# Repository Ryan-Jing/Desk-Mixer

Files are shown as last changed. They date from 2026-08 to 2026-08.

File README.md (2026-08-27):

# Desk-Mixer

A desk-top two-deck music mixer. Two tracks play at once; physical faders, knobs and buttons let
you crossfade, filter and vary the tempo of each while an LCD shows what is loaded. A companion
app on your laptop puts music on it.

Built on a **Teensy 4.1** on a custom PCB.

---

## Repository

| Path | What |
|---|---|
| [`Firmware/`](Firmware/) | Firmware — PlatformIO, C++ |
| [`App/`](App/) | Companion app — Python + PySide6 |
| [`Electrical/`](Electrical/) | Schematics and board — KiCad |
| [`Docs/`](Docs/) | Engineering source of truth |
| [`Tools/`](Tools/) | Cross-project code generation and checks |

## Hardware at a glance

| Function | Part |
|---|---|
| MCU | Teensy 4.1 — i.MX RT1062, 600 MHz Cortex-M7 |
| Audio codec | SGTL5000 → 3.5 mm jack, via I2S1 |
| Bluetooth audio | BM83SM1-00TA, fed digitally over I2S2 |
| Storage | microSD, native 4-bit SDIO |
| Power | USB-C → TUSB320 CC → TPS259251 eFuse → TPSM82903 buck |

Both I2S peripherals run at once, so the analog and Bluetooth outputs are independent and
Bluetooth needs no analog round trip.

## How music gets on it

```
Spotify playlist  ──►  metadata only (titles, artists, ISRC)
                            │
                    TrackResolver  ──►  a local audio file you own
                            │
                    ffmpeg  ──►  16-bit 44.1 kHz stereo WAV
                            │
                    USB serial  ──►  SD card  /library/<playlist>/<track>.wav
```

Spotify is never asked for audio — that is a deliberate boundary, not a gap.
See [ADR 0004](Docs/decisions/0004-track-resolver.md).

## Quick start

```sh
# firmware
cd Firmware
pio run -e teensy41            # build
pio test -e native             # host unit tests (once suites exist)

# companion app
cd ../App
python3 -m venv .venv && .venv/bin/python -m pip install -e '.[dev]'
.venv/bin/ruff check .         # tests and type checks once modules exist
```

Enable the shared pre-push gate once:

```sh
git config core.hooksPath .githooks
```

## Documentation

| Read this | For |
|---|---|
| [architecture.md](Docs/architecture.md) | how the three pieces fit together |
| [pinout.md](Docs/pinout.md) | the Teensy pin map — source of truth |
| [audio-architecture.md](Docs/audio-architecture.md) | the audio graph, timing and CPU budget |
| [protocol.md](Docs/protocol.md) | the app ↔ device wire protocol |
| [sd-layout.md](Docs/sd-layout.md) | what lives on the card |
| [testing.md](Docs/testing.md) | the test strategy, and what it deliberately does not cover |
| [decisions/](Docs/decisions/) | why things are the way they are |
| [claude-setup-guide.md](Docs/claude-setup-guide.md) | configuring Claude Code for this repo |

## Two things worth knowing up front

**USB audio out does not work.** The USB-C on the host header has no software path: `USBHost_t36`
has no USB Audio Class driver, none exists for Teensy, and the host stack's isochronous support is
unreliable. The firmware reports that output as unavailable rather than pretending.
[ADR 0005](Docs/decisions/0005-usb-host-audio.md) covers the alternatives.

**The BM83 must be switched to Host Mode** with Microchip's Config Tool before its UART responds
to anything. It ships in Embedded Mode. [ADR 0003](Docs/decisions/0003-bluetooth-bm83.md).

## Status

| Area | State |
|---|---|
| Firmware | **scaffolding only** — bare superloop in `main.cpp`, builds clean. Module breakdown deliberately undecided |
| Companion app | **scaffolding only** — design and build order in [`App/README.md`](App/README.md) |
| Wire protocol | **specified**, with generators for both sides written but parked until each side picks a layout |
| Display | **panel not yet chosen** |
| Control surface | provisional pin map; `Interface.kicad_sch` is empty |
| PCB | 36 footprints placed, **no routing yet** |

Firmware is written by Ryan, with the architecture worked out collaboratively — integration notes
per subsystem are in [`Firmware/README.md`](Firmware/README.md). The app is unbuilt; its design and
a step-by-step build order are in [`App/README.md`](App/README.md).

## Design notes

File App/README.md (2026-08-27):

# Desk-Mixer — Companion App

Reads your Spotify playlists, finds the audio, converts it to the format the device plays, and
transfers it over USB.

**Status: scaffolding only.** `pyproject.toml` and an empty package. Nothing is implemented. This
README is the design and the build order — follow it top to bottom.

---

## What it does

```
Spotify Web API          OAuth 2.0 + PKCE, read-only scopes
      │                  playlists, titles, artists, durations, ISRCs
      ▼
TrackResolver            given metadata, return a local audio file
      │                  the extension point — see below
      ▼
ffmpeg                   → 16-bit 44.1 kHz stereo WAV
      │
      ▼
Serial transfer          FILE_BEGIN → FILE_CHUNK ×N → FILE_END, CRC-32 verified
      │
      ▼
device SD card           /library/<playlist>/<track>.wav
```

Spotify supplies **metadata only**. It is never asked for audio — see
[ADR 0004](../Docs/decisions/0004-track-resolver.md).

---

## Setup

```sh
python3 -m venv .venv
.venv/bin/python -m pip install -e '.[dev]'
```

`ffmpeg` must be on PATH (`brew install ffmpeg`).

⚠️ **A venv hardcodes absolute paths.** If this directory is ever moved or renamed, delete `.venv`
and recreate it — the console scripts will otherwise point at the old location.

---

## Build order

Each step is independently testable and depends only on the ones above it. Resisting the urge to
start with the UI is the single most useful discipline here — it is the thinnest layer and the most
likely to change.

| # | Build | Why here | Needs |
|---|---|---|---|
| 1 | **Wire protocol** — framing, CRC-16, decoder | Pure byte-in/byte-out. Fully testable with zero dependencies, and the reference vectors already exist | nothing |
| 2 | **Transport** — serial + a loopback fake | The fake is what lets steps 7–8 be built and tested without hardware | pyserial |
| 3 | **Transcode** — ffmpeg wrapper | Small, self-contained, and the output format is already fixed | ffmpeg |
| 4 | **Resolver interface** + local-library resolver | Defines the contract before anything depends on it. No network | mutagen |
| 5 | **Spotify auth + client** | First step needing credentials and network | requests, a client ID |
| 6 | **YouTube resolver** | Slots into the step-4 contract | yt-dlp |
| 7 | **Manifest + library index** | Needs the resolver to have something to record | — |
| 8 | **Transfer orchestration** | Ties 1–7 together | — |
| 9 | **UI** | Last. Thin by design | PySide6 |

A useful checkpoint: after step 3 you can transcode a file by hand; after step 8 you have a working
CLI and the device can be loaded. The UI is genuinely optional until then.

---

## Layering

```
spotify/     OAuth PKCE + Web API client   — metadata only, never audio
resolve/     TrackResolver contract + implementations
transcode/   ffmpeg wrapper
device/      protocol, transport, transfer
library/     playlist manifests, SD index
ui/          PySide6 views
```

**`ui/` may call anything; nothing may call `ui/`.** Everything else must be usable headless —
that is what makes it testable and what keeps a CLI possible. If logic is hard to test, it is
almost always in the wrong layer.

---

## Implementation notes

### 1. Wire protocol

Full spec in [`Docs/protocol.md`](../Docs/protocol.md). Opcodes and constants come from
`Tools/protocol.toml` — generation is currently parked, so either hand-write them and keep them in
step, or point `PY_OUT` in `Tools/generate_protocol.py` at wherever the module should live and let
it emit them.

```
┌──────┬────────┬──────────────┬───────────────┬───────────┐
│ sync │ opcode │ length (LE16)│  payload      │ crc (LE16)│
│ 0xA5 │  1 B   │     2 B      │  0..512 B     │    2 B    │
└──────┴────────┴──────────────┴───────────────┴───────────┘
```

CRC is **CRC-16/CCITT-FALSE** (poly `0x1021`, seed `0xFFFF`) over *opcode + length + payload* —
everything except the sync byte. Max payload 512 bytes, matching the USB high-speed CDC packet.

The decoder must **discard anything that is not a sync byte while idle**. That is what lets the link
recover after a corrupt frame instead of one dropped byte killing a long transfer.

> **Pin these with tests from the start.** The firmware implements the same framing independently,
> so these vectors are what turn a silent divergence into a failing test:
> ```
> crc16(b"123456789")                     == 0x29B1
> encode(FILE_CHUNK, 01 02 03 04 05).hex() == "a52105000102030405" "2af6"
> encode(PING).hex()                       == "a5010000acfb"
> ```

### 2. Transport

Wrap pyserial behind a small `Protocol` interface with `write` / `read` / `close`, then write a
`LoopbackTransport` that records what was written and can hand back scripted replies.

That fake is worth building *before* anything uses it: it lets the whole transfer flow — including
the device rejecting a command — be exercised with no hardware attached. Teensy USB VID is `0x16C0`
for port auto-detection.

### 3. Transcode

The device plays one format only, so every source funnels through this:

```
ffmpeg -hide_banner -loglevel error -nostdin -y -i <src>
       -map a:0 -vn -ar 44100 -ac 2 -acodec pcm_s16le -f wav <dst>
```

**Build the argument vector separately from running it.** Then the command can be asserted in tests
without invoking ffmpeg, which keeps the test suite fast and hermetic.

Size estimate for space checks before a transfer: `44 + (duration_ms × 44100 / 1000) × 2 × 2` bytes,
about **10 MB per minute**. Check free space before starting — a part-written track is worse than
one never started.

On failure, delete the partial output. A truncated WAV fails at play time, far from the transfer
that caused it.

### 4. Resolver

The extension point that keeps the core neutral about where audio comes from:

```python
class TrackResolver(Protocol):
    name: str
    def resolve(self, track: TrackMeta) -> ResolveResult: ...
```

Two rules that matter:

- **Never raise for an unresolvable track.** Return a failed result carrying a *reason*. One bad
  track must not abort a playlist of sixty.
- **Report the best failure**, not the last one, when everything misses — the user needs to know
  *why* nothing matched.

`LocalLibraryResolver` matches **ISRC first** (exact, confidence 1.0), then normalised
artist/title. Normalisation should strip accents, punctuation, and **bracketed qualifiers** —
"Song (Remastered 2011)" and "Song [Live]" are the single largest cause of false negatives across
catalogues. Fall back to filename parsing (`Artist - Title.ext`) when tags are missing; a file
without tags is not an error.

### 5. Spotify

OAuth 2.0 with **PKCE** — this is a desktop app and therefore a public client, so there is no
secret to protect. Scopes are read-only: `playlist-read-private`, `playlist-read-collaborative`.
The app must never request write access.

- Verifier: 64 random bytes, base64url, unpadded. Challenge: S256 of the verifier, base64url,
  unpadded.
- Redirect to a **loopback** URI (`http://127.0.0.1:<port>/callback`); carry an opaque `state` and
  check it on return.
- Endpoints: `GET /v1/me/playlists`, `GET /v1/playlists/{id}/tracks`. Both paginate — follow `next`.
- Skip `is_local` tracks and null entries; playlist payloads routinely contain both.
- Pull **ISRC** from `external_ids` — it is by far the most reliable match key.

⚠️ **Access is single-user.** Spotify apps stay in development mode (~25 manually-added users)
unless they grant a quota extension, which they rarely do for non-commercial projects. Accepted:
this is Ryan's own device.

Map the API payload to `TrackMeta` in a **free function**, so it can be tested against captured JSON
with no network.

### 6. YouTube resolver

Slots into the step-4 contract. Two things to plan for:

- **`yt-dlp` breaks whenever the site changes.** Treat it as a dependency needing maintenance, and
  fail with a clear message rather than a stack trace.
- **Matching is the real problem, not downloading.** Covers, live takes and sped-up edits all
  resolve to plausible-looking videos. **Duration is the cheapest sanity check** — reject anything
  more than a few seconds from the Spotify metadata, and prefer results whose title contains the
  artist.

Quality context: lossy → WAV **preserves** the source, it does not improve it. Given the device ends
in SBC Bluetooth or a modest headphone amp, that is a fine trade — see
[ADR 0004](../Docs/decisions/0004-track-resolver.md).

### 7. Manifest

Written beside the audio on the card. Records what *should* be present, **including what could not
be resolved and why**, so a later sync does not have to re-derive intent from filenames.

```json
{
  "name": "Late Night Set",
  "source_id": "spotify:playlist:...",
  "entries": [
    { "title": "...", "artist": "...", "remote_path": "/library/Late Night Set/....wav",
      "isrc": "...", "duration_ms": 449000, "resolver": "local" }
  ],
  "unresolved": ["Some Track — not found in local library"]
}
```

The firmware does not read it — it enumerates directories directly, so the card works even if the
manifest is stale or missing. This is for the app and for humans.

### 8. Transfer

```
FILE_BEGIN (uint32 size, utf-8 path) ──► ACK
FILE_CHUNK (≤512 B)                  ──► ACK    … repeated
FILE_END   (uint32 crc32)            ──► ACK
```

CRC-32 is IEEE 802.3 (`zlib.crc32`), computed over the whole file. The device verifies before
committing and deletes the partial file on mismatch.

⚠️ **Never transfer while the device is playing.** SD write bursts stall the reads feeding the audio
engine, which is the classic dropout cause. The firmware should enforce this as a hard interlock,
but the app should not attempt it either.

Names are sanitised to **ASCII** before writing: transliterate accents (`Björk` → `Bjork`), replace
anything else with `_`, and never produce an empty name. The firmware holds names in fixed byte
buffers and renders them with a simple font, so a multi-byte character risks being truncated
mid-sequence.

### 9. UI

Thin. It owns no business logic — everything it shows comes from the headless layers. A playlist
list, a transfer button, a progress bar and a status line covering device presence and ffmpeg
availability is enough for v1.

---

## Testing

```sh
.venv/bin/python -m pytest
.venv/bin/ruff check . && .venv/bin/mypy
```

**No test may touch the network, a real serial port, or a real ffmpeg binary.** That is achievable
throughout if the layering above holds:

| Area | How to test it hermetically |
|---|---|
| protocol | reference vectors, round trips, corruption, resynchronisation |
| transport | `LoopbackTransport` playing a fake device that ACKs or NACKs |
| transcode | assert the argument vector; never invoke ffmpeg |
| resolver | a `tmp_path` folder of dummy audio files |
| spotify | captured JSON payloads through the mapping function |
| transfer | loopback fake, including the rejection paths |

Write the protocol tests **first** — they are the contract with the firmware, and they cost nothing
to run.

---

## Configuration and secrets

Nothing secret belongs in the repository. PKCE needs no client secret, but a **client ID** from the
Spotify developer dashboard is required.

```
~/.config/desk-mixer/settings.json        client ID, music folders, serial port, ffmpeg path
~/.config/desk-mixer/spotify-token.json   cached token — chmod 0600
```

Use `platformdirs` rather than hardcoding, and make loading tolerant of a missing or corrupt file by
falling back to defaults.

A `--doctor` command that reports ffmpeg availability, visible serial ports, configured music
folders and whether a client ID is set is worth building early — it must work **without PySide6**,
so import the UI lazily.

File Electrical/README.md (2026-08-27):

# Desk-Mixer — PCB

KiCad 10 project (`Desk-DJ`). **Four-layer**, 1.6 mm FR4.

> **This directory is hand-edited in KiCad.** Nothing else in this repository modifies it, and
> tooling should not either — editing `.kicad_sch` or `.kicad_pcb` as text corrupts UUIDs and net
> linkage.

## Sheets

| Sheet | State |
|---|---|
| `USB_Input.kicad_sch` | USB-C power input: `USBLC6-2SC6` ESD → `TUSB320` CC → eFuse |
| `Power.kicad_sch` | `TPS259251` eFuse → `TPSM82903` buck → +3V3. Most complete sheet |
| `Microcontrollers.kicad_sch` | Teensy 4.1 pin budget assigned; BM83 placed but unwired |
| `Audio_IO.kicad_sch` | SGTL5000 I2S/I²C/headphone out, `SJ1-3525N` jack. No power section yet |
| `LCD.kicad_sch` | **empty** |
| `Interface.kicad_sch` | **empty** |

The board has 36 footprints imported and **no tracks, pours or outline**.

Four layers rather than two: the stackup has to give an uninterrupted ground plane under the USB
differential pairs and both I2S MCLK lines. Those are 11.29 MHz square waves running near the
analog section, and on two layers you end up choosing which of impedance control or analog
isolation to compromise.

## What firmware depends on

The pin map lives in [`Docs/pinout.md`](../Docs/pinout.md) and
`Firmware/include/config.h`, both derived from this schematic.

**If they disagree with the schematic, the schematic wins.** Flag the discrepancy rather than
editing either side silently.

## BM83 — what the board must provide

Use **`BM83SM1-00TA`** (Audio Transceiver firmware, A2DP source), not `-00AB` (speaker linking).

Beyond I2S2 and the UART, three control lines need Teensy GPIOs: `MFB` (26), `RST_N` (43) and
`P3_4` (31). `P3_4` and `RST_N` are what let the Teensy put the module into flash mode and act as a
serial relay for Microchip's PC tools — which is how a soldered module stays recoverable without a
programming header or USB traces to the module.

No copper, traces or components beneath the module's PCB antenna.

## Open items

A read of the netlist on 2026-08-26 turned up several things worth checking next time this is
open — an I²C net-name mismatch, a power-button symbol that is actually an LDO, the SGTL5000's
missing power section, and the unwired BM83 among them. They are recorded in
[ADR 0006](../Docs/decisions/0006-electrical-review.md) as reference, not as a task list.

## Portability warning

Every non-stock symbol and footprint resolves through the **global** KiCad library table at
`~/Local/System-Local/Packages/KiCad/…`, outside this repository. Cloning the repo on another
machine will break all of them. Vendoring the project libraries under this directory would fix it.

## Ignored files

`.gitignore` excludes KiCad's per-user state: `*.kicad_prl`, `fp-info-cache`, `*-backups/`,
`_restore_backup_*/`, lock files, and `.history/`. That last one is KiCad 10's Local History,
which keeps its **own nested git repository** — it was previously picked up as a gitlink with no
`.gitmodules`, which breaks `git submodule status`.

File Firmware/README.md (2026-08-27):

# Desk-Mixer — Teensy 4.1 Firmware

Two-deck audio playback, mixing and control-surface handling.

**Status: scaffolding only.** `src/main.cpp` holds a bare superloop and nothing else. The module
breakdown is deliberately undecided — hardware is not finalised, and the structure should follow
the hardware rather than lead it. This README is the integration reference to build against.

---

## Build

```sh
pio run -e teensy41            # build
pio run -e teensy41 -t upload  # flash
pio device monitor             # serial console
pio test -e native             # host unit tests (once suites exist)
```

Current footprint: ~9.5 kB flash, of 7.75 MB. Effectively all of it is still free.

---

## Hardware

| Function | Part | Interface |
|---|---|---|
| MCU | **Teensy 4.1** (i.MX RT1062, 600 MHz Cortex-M7) | — |
| Audio codec | **SGTL5000** | I2S1 + I²C `0x0A` |
| Bluetooth audio | **BM83SM1-00TA** | I2S2 (audio) + UART (control) |
| Storage | microSD | native 4-bit SDIO (`BUILTIN_SDCARD`) |
| Display | SPI panel, **not yet selected** | SPI |
| Host link | USB CDC serial | Teensy device port |

### Clock and data pins — fixed by the silicon

| Bus | MCLK | BCLK | LRCLK | TX | RX |
|---|---|---|---|---|---|
| I2S1 (SAI1) → SGTL5000 | 23 | 21 | 20 | **7** | **8** |
| I2S2 (SAI2) → BM83 | 33 | 4 | 3 | 2 | 5 |

SAI1 and SAI2 are independent peripherals, so **both run at once**. The analog jack and Bluetooth
are fed from separate buses, and Bluetooth gets a digital feed with no analog round trip.

S/PDIF is available on pin 14 and currently unused. Full map: [`Docs/pinout.md`](../Docs/pinout.md).

### USB

- **Device** — the micro-USB port, reached on the PCB via pogo pins to the bottom-side D+/D− test
  pads when the Teensy is seated in its header. Power and data both come from the panel USB-C, so
  the Teensy sees one host and one supply — no pads or traces need cutting, and the board can still
  be flashed standalone through its own micro-USB when removed.
  ⚠️ The receptacle and those pads are the **same electrical node**, so **never connect the panel
  port and the micro-USB at the same time** — that ties two hosts' VBUS together.
- **Host** — the 5-pin header, wired to a USB-C connector for audio out. **There is no USB Audio
  Class host driver for Teensy**, so this path has no software route today. See
  [ADR 0005](../Docs/decisions/0005-usb-host-audio.md).

---

## The superloop

`main.cpp` runs fixed-cadence tasks against `millis()`:

```c
if ((now - s_last_control_ms) >= CONTROL_PERIOD_MS) {
    s_last_control_ms = now;
    control_task();
}
```

Chosen over an RTOS because the Teensy audio library already preempts from an interrupt, so the
loop's only job is to run each task often enough. Fixed cadences make every task's worst-case
latency obvious by reading the file — no priority inversion, no stack sizing, no scheduler to
reason about.

**The one rule: nothing in the loop may block.** No `delay()`, no busy-wait, no spin on a peripheral
flag. A task that needs to wait returns and resumes on the next tick.

### Adding a task

Add a period macro, a `s_last_*_ms` timestamp, and a branch. Keep the cadence honest: a task that
runs every 1 ms must actually complete in well under 1 ms.

Starting cadences, adjust once there is something to measure:

| Task | Period | Why |
|---|---|---|
| control surface | 1 ms | responsiveness — this is what makes the device feel tight |
| host link / UARTs | 2 ms | drain buffers before they overflow, but do not starve controls |
| display | 30 ms | ~33 fps; SPI refresh is expensive and the eye is not |

### When the superloop stops being enough

Watch for: a task that cannot complete inside its cadence, or work that must happen at a precise
time rather than "soon". The usual escalations, roughly in order of cost:

1. **Split the long task** across ticks with a small state machine. Cheapest, and usually enough.
2. **Move it to an interrupt** — `IntervalTimer` for periodic work, or a peripheral ISR.
3. **Use DMA** for bulk transfers, so the CPU is not the bottleneck.
4. **Adopt an RTOS** (`TeensyThreads` or FreeRTOS). Only worth it if several tasks genuinely need
   independent blocking; it brings stack sizing and priority questions the superloop avoids.

The audio engine is already effectively option 2 — it runs from the SAI interrupt regardless.

---

## Integration notes

Reference material for each subsystem. **None of this is implemented.**

### Audio — the 2.9 ms deadline

128 samples at 44.1 kHz means one block every **2.9 ms**, 344 times a second. Every audio object's
`update()` runs inside that window at interrupt priority. Overrunning it does not slow the device
down; it drops audio.

Inside any audio callback: **no heap, no blocking, no `Serial`, no unbounded loops.**

The Teensy Audio Library builds a static graph of `AudioStream` objects wired by `AudioConnection`
objects at file scope. A two-deck mixer shape:

```
player A ─► filter ─┐
                    ├─► mixer L/R ─┬─► AudioOutputI2S  ─► SGTL5000 ─► jack
player B ─► filter ─┘              └─► AudioOutputI2S2 ─► BM83 ─► Bluetooth
```

Practical notes:

- `AudioMemory(n)` allocates the block pool. Start around 60 and tune against
  `AudioMemoryUsageMax()`; if usage reaches the allocation, blocks are being starved.
- `AudioProcessorUsageMax()` gives peak CPU as a percentage. Keep it well under ~70 % so transients
  have headroom.
- `AudioConnection` objects exist purely for their constructor side effect. cppcheck reads them as
  unused, which is why `unusedVariable` is suppressed in `.cppcheck-suppressions`.
- Both I2S outputs can be fed permanently. Muting a sink on output switch causes a click; leaving
  both connected and changing only what the UI calls "active" avoids it.

**Varispeed.** The stock library has no variable-rate SD player. `AudioPlaySdResmp` from
[`teensy-variable-playback`](https://github.com/newdigate/teensy-variable-playback) resamples on the
fly — pitch and tempo move together, like a turntable. Its transport API is narrower than it looks
and is worth reading before designing around it:

- `playWav(path)` is the **only** way to start, and always begins at the configured play-start point
- `stop()` clears the playing flag but **does not rewind**
- there is **no `play()`** and no seek

So resume has to be expressed as *set the play-start point, then re-open*, where `setPlayStart`
takes **frames** (per-channel samples), not bytes or milliseconds:

```c
uint32_t frames = (uint32_t)(((uint64_t)position_ms * 44100u) / 1000u);
player.setPlayStart(play_start_arbitrary, frames);
player.playWav(path);
```

Key-lock (WSOLA time-stretch) costs roughly half a core when active — probably a v2 question.

### SGTL5000

`AudioControlSGTL5000` from the stock library. I²C address `0x0A` by default, `0x2A` if the address
pin is pulled high. `enable()` must succeed before audio flows; treat failure as "no analog output"
rather than a fatal error. `volume()` drives the headphone amp, `lineOutLevel()` the line output.

The codec needs its analog supply and charge-pump capacitors in place before it will respond — NXP
**AN3663** is the reference layout.

### BM83 Bluetooth

The device **transmits** to Bluetooth headphones — the A2DP **source** role. Use the
**`BM83SM1-00TA`**, which ships with Microchip's Audio Transceiver firmware and supports source.
The `BM83SM1-00AB` is the Wireless Concert Technology variant for speaker-to-speaker linking and is
the wrong part here.

The TX encoder is **SBC** at 44.1/48 kHz, so the Bluetooth path is capped at SBC quality regardless
of what is on the card.

**The Teensy is the I2S master; the BM83 is the slave.** MCLK is mandatory in slave mode — the
module is strict about clock synchronisation, and `AudioOutputI2S2` drives it on pin 33.

| Signal | Teensy | BM83 |
|---|---|---|
| BCLK | 21 | `SCLK1` (3) |
| LRCLK | 20 | `RFS1` (2) |
| Audio data out | 2 | `DT1` (4) |
| MCLK | 33 | `MCLK1` (5) |
| UART out | 1 (`TX1`) | `HCI_RXD` (13) |
| UART in | 0 (`RX1`) | `HCI_TXD` (12) |
| Reset | *TBD* | `RST_N` (43) |
| Wake | *TBD* | `MFB` (26) |
| Boot mode | *TBD* | `P3_4` (31) |

⚠️ **Three of those GPIOs are unallocated**, and nothing works without them. `MFB` must go **high
2–3 ms before every UART command** to wake the module from power save; `BM83_EN` is a supply enable
and does not cover it. `RST_N` and `P3_4` are what make in-system flashing possible.

### Provisioning and the serial relay

A fresh `-00TA` already has the right firmware, so what it needs is a **configuration** write:
Host Mode, I2S role **Slave**, I2S path **Input**. Without that the UART does not answer and the
module may try to drive the I2S clocks itself.

Flashing is done by a **PC**, over the module's UART — but it can go **through the Teensy**, which
is the chosen route and needs no extra connector or USB traces to the module:

1. Teensy drives `P3_4` low and pulses `RST_N` → module enters test/flash mode.
2. Teensy runs a transparent serial relay: USB `Serial` ↔ `Serial1`.
3. On the PC, `isUpdate` or the Config GUI Tool selects the **Teensy's COM port**, transport UART.
4. Teensy drives `P3_4` high and resets → app mode.

**The relay is a firmware deliverable.** Small, but it must be transparent about baud and must not
buffer or reorder in a way the tool's timing notices.

An unprovisioned module is silent and gives no diagnostic, so the failure looks exactly like a
wiring fault. Proving the chain on an EVB first separates "not configured" from "wired wrong".

**Antenna keep-out:** no copper, traces or components beneath the module's PCB antenna.

**No Arduino or Teensy library exists**, so the driver is ours. Packet format is in Microchip
**DS50002896A** (*BM83 Host MCU Firmware Development Guide*); reference source, written for PIC32,
is at [`MicrochipTech/bm83_getting_started`](https://github.com/MicrochipTech/bm83_getting_started).

Framing, from that document:

```
[0]    0xAA start byte
[1..2] payload length, BIG-endian, counting opcode + parameters
[3]    opcode
[4..]  parameters
[n]    checksum: two's complement of the sum of every byte after the start byte
```

A well-formed packet's bytes after the start byte sum to zero modulo 256 — that is the property to
verify against. Note the length is **big-endian and counts the opcode**, the opposite of the host
link protocol below; do not copy one codec into the other.

Bluetooth adds 150–300 ms of latency. The wired jack is the monitoring output for beat-matching;
Bluetooth is an audience output, and its metering should not be presented as real-time.

### SD card

Built-in socket on native **4-bit SDIO** via `SD.begin(BUILTIN_SDCARD)` — not SPI, and much faster.
Teensyduino ships `SD 2.0.0` as a wrapper over `SdFat 2.1.2`; drop to `SdFat` directly if you need
its faster APIs or exFAT specifics.

**Audio streams; nothing is loaded whole.** A 4-minute WAV is ~42 MB against 1 MB of RAM, so the
player refills a small buffer from the card while the audio interrupt drains 128 samples every
2.9 ms.

| | |
|---|---|
| One stereo deck | 176.4 kB/s |
| Two decks | **352.8 kB/s** |
| SDIO capability | many MB/s |

So throughput was never the risk — **latency spikes** are. A 32 kB buffer per deck is ~186 ms of
cushion, which is ample against SD read jitter. `AudioPlaySdResmp` buffers more than the stock
player because resampling needs lookahead, and can move that buffer to PSRAM if it is ever needed.

**Never write to the card while playing.** Card write bursts stall reads, and that is the classic
dropout cause. Transfers are rare — a few times a year — so this costs nothing. Make it a hard
interlock in firmware: refuse `FILE_BEGIN` unless both decks are stopped, rather than trusting the
app to behave.

Teensy 4.1 has pads for **8 MB PSRAM**, which can be added later if buffering ever needs it.

Card layout and the WAV-only decision: [`Docs/sd-layout.md`](../Docs/sd-layout.md),
[ADR 0002](../Docs/decisions/0002-wav-not-mp3.md).

### Display

Panel not chosen. Worth keeping the drawing calls behind a small surface of your own so the concrete
driver can be swapped without touching UI logic — the panel decision and the menu logic are
independent problems.

The `DISP_*` nets are already assigned (see the pinout). SPI refresh is slow relative to everything
else, so buffer draws and push once per display tick rather than writing through.

### Control surface

Teensy 4.1 has 18 ADC-capable pins, enough for the full fader/knob budget with no multiplexer.
Encoders belong on the **hardware quadrature timer pins**, where decoding costs zero CPU.

Two things worth handling early, because they are invisible until they annoy you: cheap pots dither
by a couple of counts, so a small hysteresis stops the audio engine being told to change gain every
tick; and pots rarely reach their electrical extremes, so an end deadzone is what makes a closed
fader actually silent.

`Interface.kicad_sch` is still empty, so the pin allocation is provisional.

**Jack insertion is detectable.** `J3` is an `SJ1-3525N`, the tip-and-ring switch variant — the
switches are normally closed to their contacts and open when a plug is inserted. Because the switch
shorts to the audio tip, a plain pull-up reads high in both states; see `Docs/pinout.md` for a
divider that works. Currently unwired and unallocated.

### Host link

USB type is **`USB_MIDI_SERIAL`**, set in `platformio.ini`. That gives a CDC serial port for the
companion app plus a MIDI device, so the mixer can double as a control surface for Mixxx or Traktor.

USB type is compile-time and exclusive — MTP and USB Audio cannot be added to this combination. See
[ADR 0001](../Docs/decisions/0001-usb-port-roles.md).

The wire protocol is specified in [`Docs/protocol.md`](../Docs/protocol.md) and generated from
`Tools/protocol.toml`. The app side is implemented and tested; **the firmware side is not written**.
Generation into the firmware tree is currently switched off — set `H_OUT` in
`Tools/generate_protocol.py` to wherever the header should live to turn it back on.

---

## Structure

`include/` mirrors `src/`, and there is no `lib/` folder. Beyond that the breakdown is open.

One suggestion worth weighing as modules appear: keep the parts that make *decisions* separate from
the parts that touch *hardware*. A file that includes no Arduino or Teensy headers can be compiled
and unit-tested on the laptop, which matters here because of the next section. Framing, checksums,
gain curves, menu logic and format parsing all tend to fall out this way naturally.

To wire a file into host testing, list it in `[pure] sources` in `platformio.ini`.

---

## Testing

| Tier | Command | Covers |
|---|---|---|
| Host unit | `pio test -e native` | anything with no hardware includes |
| On-target | `pio test -e teensy41_test` | SD, I²C, UART, timing |
| Static | `cppcheck` (see `.cppcheck-suppressions`) | whole tree |
| Style | `python3 ../Tools/check_style.py` | house style, mechanically |

**There is no Teensy 4.1 emulator.** No Renode or QEMU machine model exists for the i.MX RT1062,
and the peripherals that matter (SAI/I2S, SDIO) are not modelled anywhere. Host tests over
hardware-independent code, plus fakes for the rest, are the only automated option — which is the
main argument for the split suggested above.

**On-target caveat:** PlatformIO claims the first `Serial` as its test transport, so all `Serial`
use must sit inside `#ifndef UNIT_TEST`. Teensy 4.1 on-target runs are also known to stall after
upload occasionally, so that tier is a local gate, not a CI gate.

CI skips the host-test job while `test/` is empty and picks it up automatically once a suite lands.

---

## Documentation

```sh
doxygen Doxyfile && open doxygen/html/index.html
```

Doxygen emits a "member belongs to two different groups" warning for `main.cpp` — a consequence of
the house style's blank `@name` opening an anonymous member group. Cosmetic.

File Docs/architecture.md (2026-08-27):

# System architecture

## What the device is

A desk-top two-deck music mixer. Two tracks play at once; physical faders, knobs and buttons let
you crossfade, filter and vary the tempo of each. An LCD shows what is loaded. A laptop app puts
music on it.

## The three pieces

```
┌────────────────────────┐        USB CDC serial         ┌──────────────────────────┐
│  App        │◄─────────────────────────────►│  Firmware       │
│  Python + PySide6      │   custom protocol, ADR 0001   │  Teensy 4.1 firmware     │
│                        │                               │                          │
│  Spotify ─► metadata   │                               │  2 decks, mixer, DSP     │
│  Resolver ─► audio file│                               │  LCD, control surface    │
│  ffmpeg ─► WAV         │                               │  BM83 Bluetooth driver   │
└────────────────────────┘                               └──────────────────────────┘
                                                                      │
                                                         ┌────────────┴────────────┐
                                                         │   PCB        │
                                                         │   KiCad, Ryan's domain  │
                                                         └─────────────────────────┘
```

## Data flow — getting music onto the device

```
Spotify playlist          (metadata only — titles, artists, ISRC; ADR 0004)
      │
      ▼
TrackResolver             (local music library by default; pluggable)
      │  local audio file
      ▼
ffmpeg transcode          16-bit 44.1 kHz stereo WAV (ADR 0002)
      │
      ▼
USB serial transfer       FILE_BEGIN → FILE_CHUNK ×N → FILE_END, CRC-32 verified
      │
      ▼
SD card  /library/<playlist>/<track>.wav
```

Spotify is never asked for audio. That split is a deliberate constraint, not an implementation
gap — see [ADR 0004](decisions/0004-track-resolver.md).

## Data flow — playing

```
SD card ──► AudioPlaySdResmp ×2 ──► filters ──► mixer ──┬──► SGTL5000 ──► 3.5 mm jack
            (varispeed resampling)                      ├──► BM83 (I2S2) ──► Bluetooth
                                                        └──► USB host ──► ✗ no driver (ADR 0005)
```

Two independent I2S peripherals mean the analog and Bluetooth paths run **simultaneously** from
separate buses, and Bluetooth is fed digitally with no analog round trip.

Details in [audio-architecture.md](audio-architecture.md).

## Firmware structure

**Not yet decided.** `src/main.cpp` holds a bare superloop; the module breakdown will follow the
hardware rather than lead it. `include/` mirrors `src/` and there is no `lib/` folder — beyond that
the layout is open.

One structural idea carries real weight, because there is **no Teensy 4.1 emulator**: code that
includes no Arduino or Teensy headers can be compiled and unit-tested on the laptop. Separating the
parts that make *decisions* from the parts that touch *hardware* is what makes any automated
firmware testing possible at all. Framing, checksums, gain curves, menu logic and format parsing
tend to fall out that way naturally. See [testing.md](testing.md).

Integration notes for each subsystem — audio graph, BM83 framing, SD, controls — are in
[`Firmware/README.md`](../Firmware/README.md).

## Timing

Audio runs at interrupt priority on a **2.9 ms deadline** (128 samples @ 44.1 kHz). Everything
else is a cooperative superloop in `main.cpp`:

| Task | Period |
|---|---|
| control surface | 1 ms |
| host link + BM83 UART | 2 ms |
| display | 30 ms |

No RTOS. The audio engine already preempts, and fixed cadences make each task's worst-case latency
obvious by inspection.

## Where things are written down

| Question | Answer lives in |
|---|---|
| Which pin does X use? | [pinout.md](pinout.md) |
| How does the audio graph work? | [audio-architecture.md](audio-architecture.md) |
| What does the app send the device? | [protocol.md](protocol.md) |
| What is on the SD card? | [sd-layout.md](sd-layout.md) |
| How do I test this? | [testing.md](testing.md) |
| Why is it done that way? | the ADRs, starting at [0001](decisions/0001-usb-port-roles.md) |
| How do I configure Claude for this repo? | [claude-setup-guide.md](claude-setup-guide.md) |

Design thinking, component selection and to-dos live in the Obsidian vault, which points here.
Anything that must version with the code lives in this folder.

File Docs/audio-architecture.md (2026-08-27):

# Audio architecture

## The deadline

The Teensy Audio Library processes **128 samples at 44.1 kHz** — one block every **2.9 ms**,
344 times a second. Every audio object's `update()` runs inside that window at interrupt priority.

This single number governs the design. Overrunning it does not slow the device down; it drops
audio.

**Inside any `update()` or audio callback: no heap, no blocking, no `Serial`, no unbounded loops.**

## Graph

```
                     ┌────────────────────┐
AudioPlaySdResmp A ─►│ FilterStateVariable │─┐
   (SD, varispeed)   └────────────────────┘ │   ┌───────────┐
                                            ├──►│ Mixer L/R │──┬──► AudioOutputI2S   ──► SGTL5000 ──► 3.5 mm jack
                     ┌────────────────────┐ │   └───────────┘  │
AudioPlaySdResmp B ─►│ FilterStateVariable │─┘                 ├──► AudioOutputI2S2  ──► BM83 ──► Bluetooth
   (SD, varispeed)   └────────────────────┘                    │
                                                               └──► [USB host — no driver]
        │                                                                 (ADR 0005)
        └──► AudioAnalyzePeak ×2 ──► LCD level meters
```

Worth building in one place that owns **every** `AudioStream` object, so the graph can be read as a
whole and the block budget has a single home.

## Why both outputs are always fed

`AudioOutputI2S` and `AudioOutputI2S2` are separate peripherals (SAI1 and SAI2) and run
concurrently. Both mixer outputs are connected permanently; selecting an output changes what the
UI presents as active rather than muting a sink. Muting on switch would add a click every time,
for no benefit.

Feeding the BM83 over I2S2 means Bluetooth is fed **digitally** — no DAC→wire→ADC round trip.

## Playback and tempo

`AudioPlaySdResmp` from [`teensy-variable-playback`](https://github.com/newdigate/teensy-variable-playback)
resamples on the fly, so tempo and pitch move together — varispeed, like a turntable, not
time-stretch. Key-lock (WSOLA) would cost roughly half a core when active and is out of scope for v1.

Tempo range is ±8 % (`DSP_TEMPO_RANGE_PERCENT`), with a centre detent that yields **exactly 1.0**
so a centred fader is bit-accurate playback.

### Transport semantics — read this before designing the deck API

The library's API is narrower than it looks:

- `playWav(path)` is the **only** way to start. It opens the file and begins at the configured
  play-start point.
- `stop()` clears the playing flag but **does not rewind**.
- There is **no `play()`** on `AudioPlaySdResmp` and no seek.

So pause/resume is expressed as *set the play-start point, then re-open*:

| Action | Implementation |
|---|---|
| play from top | `setPlayStart(play_start_sample, 0)` → `playWav(path)` |
| pause | record `positionMillis()`, then `stop()` |
| resume | `setPlayStart(play_start_arbitrary, frames)` → `playWav(path)` |
| cue | `stop()`, clear the stored resume position |

`_playback_start` is in **frames** (per-channel samples), not bytes or milliseconds:
`frames = ms × 44100 / 1000`.

## Mixing law

`dsp_crossfade_gains()` uses a **constant-power** sin/cos law, so `gain_a² + gain_b² == 1` across
the whole sweep and a centred crossfader is not quieter than either extreme. Channel faders use a
squared taper (`dsp_fader_to_gain`), because a linear fader feels top-heavy — loudness perception
is logarithmic, so the bottom half of a linear fader is nearly unusable.

Both laws are pure arithmetic with no hardware dependency, so they are natural candidates for host
unit tests — the constant-power invariant in particular is easy to assert across the full sweep.

## Budget

The Teensy 4.1 has 7.75 MB flash and 512 kB RAM. The current scaffold uses ~9.5 kB, so essentially
all of it is available.

`AudioMemory(n)` allocates the audio block pool — around 60 is a reasonable starting point. Tune it
against `AudioMemoryUsageMax()` and `AudioProcessorUsageMax()` on hardware; if memory usage reaches
the allocation, blocks are being starved and it will be audible. Keep peak CPU well under ~70 % so
transients have headroom.

Teensy 4.1 has pads for **8 MB PSRAM**, and `AudioPlaySdResmp` can buffer there
(`setBufferInPSRAM`). Worth fitting at assembly: it is painful to add later.

## Bluetooth latency

SBC adds roughly 150–300 ms. The analog jack is the monitoring output used for beat-matching;
Bluetooth is an audience output. The UI must not present Bluetooth-derived metering as real-time.

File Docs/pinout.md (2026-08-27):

# Teensy 4.1 pin map

**Source of truth for firmware.** Derived from `Electrical/Desk-DJ.kicad_pcb`. Where this
disagrees with the schematic, **the schematic wins** — flag it rather than editing either side
silently. This document is the reference the firmware should be written against.

## Fixed-function pins

These are fixed by the i.MX RT1062 silicon and are **not reassignable**.

| Pin | Signal | Peripheral | Goes to |
|---|---|---|---|
| 7 | `I2S1_TX` / **TX_DATA0** | SAI1 | SGTL5000 `I2S_DIN` (pin 17) |
| 8 | `I2S1_RX` / **RX_DATA0** | SAI1 | SGTL5000 `I2S_DOUT` (pin 16) |
| 20 | `I2S1_LRCLK` | SAI1 | SGTL5000 |
| 21 | `I2S1_BCLK` | SAI1 | SGTL5000 |
| 23 | `I2S1_MCLK` | SAI1 | SGTL5000 |
| 2 | `I2S2_TX` / TX_DATA | SAI2 | BM83 `DT1` (pin 4) |
| 3 | `I2S2_LRCLK` | SAI2 | BM83 `RFS1` (pin 2) |
| 4 | `I2S2_BCLK` | SAI2 | BM83 `SCLK1` (pin 3) |
| 5 | `I2S2_RX` / RX_DATA | SAI2 | BM83 (unused — TX only) |
| 33 | `I2S2_MCLK` | SAI2 | BM83 `MCLK1` (pin 5) — **required** in slave mode |
| 14 | `SPDIF_OUT` | SPDIF3 | **spare** — a possible feed for a UAC bridge (ADR 0005) |
| 18 | `I2C_SDA` | LPI2C | SGTL5000 (`0x0A`), TUSB320 |
| 19 | `I2C_SCL` | LPI2C | SGTL5000, TUSB320 — ⚠️ see note |
| — | SDIO ×6 | USDHC1 | built-in microSD (`BUILTIN_SDCARD`) |

> ⚠️ Two schematic issues affect this table, both recorded in
> [ADR 0006](decisions/0006-electrical-review.md):
>
> 1. Teensy pin 19 sits on a net named `I2C_SDL` while the codec is on `I2C_SCL`.
> 2. **The I2S1 data lines are swapped at the Teensy.** Pad 7 carries `I2S1_TEENSY_IN` but is the
>    silicon's `TX_DATA0`; pad 8 carries `I2S1_TEENSY_OUT` but is `RX_DATA0`. As drawn, the codec's
>    `I2S_DOUT` and the Teensy's transmitter drive the same net. I2S2 is wired correctly.

## Display — SPI

Panel not yet selected. These follow the `DISP_*` nets already assigned.

| Pin | Net | Function |
|---|---|---|
| 6 | `DISP_BCKLT` | backlight enable |
| 9 | `DISP_DC` | data/command |
| 10 | `DISP_CS` | chip select |
| 11 | `DISP_MOSI` | SPI MOSI |
| 12 | `DISP_MISO` | SPI MISO |
| 13 | `DISP_SCK` | SPI clock |
| 32 | `DISP_RST` | reset |

## Bluetooth and power sequencing

| Pin | Net | Function |
|---|---|---|
| 0 / 1 | `RX1` / `TX1` | `Serial1` → BM83 `HCI_RXD` (13) / ← `HCI_TXD` (12) |
| 28 | `BM83_EN` | BM83 supply enable |
| *TBD* | `BM83_MFB` | BM83 `MFB` (pin 26) — ⚠️ **unassigned**. High 2–3 ms before every UART command |
| *TBD* | `BM83_RST_N` | BM83 `RST_N` (pin 43) — ⚠️ **unassigned**. Active low; also wanted on a button |
| *TBD* | `BM83_P3_4` | BM83 `P3_4` (pin 31) — ⚠️ **unassigned**. High = app mode, low = test/flash mode |
| 29 | `3V3_EN` | 3.3 V rail enable |
| 34 | `3V3_PG` | 3.3 V power-good |
| 30 | `USBC_AUDIO_DET` | USB-C audio port detect |
| 35 | `USBC_AUDIO_EN` | USB-C audio port switch enable |
| 31 | `USBC_5V_FLT` | 5 V current-limit fault |

## Control surface

`USR_CTRL_0..9` are netlisted on the Teensy but `Interface.kicad_sch` is empty, so the
allocation below is **provisional**.

| Pin | Net | Provisional use |
|---|---|---|
| 14 | `USR_CTRL_0` | crossfader |
| 15 | `USR_CTRL_1` | deck A gain |
| 16 | `USR_CTRL_2` | deck B gain |
| 17 | `USR_CTRL_3` | deck A tempo |
| 24 | `USR_CTRL_4` | deck B tempo |
| 25 | `USR_CTRL_5` | deck A filter |
| 26 | `USR_CTRL_6` | deck B filter |
| 27 | `USR_CTRL_7` | *unassigned* |
| 38 | `USR_CTRL_8` | select button |
| 39 | `USR_CTRL_9` | back button |

Pins 14–17 and 24–27 are ADC-capable, which is why the pots sit there. Encoders, when added,
should go on the hardware quadrature timer pins so decoding costs no CPU.

## USB

| Bus | Where | Carries |
|---|---|---|
| Device | micro-USB, reached by **pogo pins to the bottom-side D+/D− test pads** | 5 V power, flashing, companion-app link |
| Host | 5-pin header | intended USB-C audio out — **no driver**, see [ADR 0005](decisions/0005-usb-host-audio.md) |

⚠️ The micro-B receptacle and the bottom D+/D− pads are the **same electrical node**. Only one may
be connected at a time; back-powering a host port can damage the host controller.

## Jack insertion detect

`J3` is an **SJ1-3525N**, the tip-and-ring switch variant: pin 1 sleeve, 2 tip, 3 ring,
**10 tip switch**, **11 ring switch**. The switches are normally closed to their contacts and open
when a plug is inserted, so insertion detection is possible.

The nets `TIP_SW_DET` and `RING_SW_DET` exist on `J3` but are **one-ended** — they do not reach a
GPIO yet, and no Teensy pin is allocated.

Because the switch shorts to the *tip*, which is an audio node, a plain pull-up will not work —
both states read high. A network that does work:

- **1 MΩ pull-up** from pin 10 to +3V3
- **100 kΩ** from the jack-side tip to GND
- series resistor plus a small cap at the GPIO, for ESD and debounce

No plug: the divider reads roughly 0.3 V (low). Plug inserted: pin 10 floats to 3.3 V (high). The
100 kΩ is negligible against a 32 Ω headphone load.

## Unassigned

Pins **22, 36, 37, 40, 41** are free — five pins against four known claimants:

| Wanted for | Why |
|---|---|
| `BM83_MFB` | wake the module before every UART command |
| `BM83_RST_N` | reset, and part of the flash-mode entry sequence |
| `BM83_P3_4` | boot mode select — this is what makes in-system flashing possible |
| jack detect | headphone insertion |

That leaves one spare. Pins 24–27 are partly spoken for by the control surface above.

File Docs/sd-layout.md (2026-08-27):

# SD card layout

## Card

Built-in socket, native **4-bit SDIO** (`BUILTIN_SDCARD`), not SPI. Formatted **FAT32 or exFAT**.

Use a decent card. Sustained read matters: two decks of 16-bit 44.1 kHz stereo is ~352 kB/s
combined, and the audio engine cannot wait.

**Never write to the card while audio is playing.** Card write bursts stall reads, which is the
classic cause of audio dropouts. Transfers happen a few times a year, so this costs nothing in
practice — but it should be a hard interlock in firmware, refusing `FILE_BEGIN` unless both decks
are stopped, rather than a rule the app is trusted to follow.

## Directory structure

Deliberately plain, so the card stays browsable on a computer and needs no index to interpret.

```
/library/
├── Late Night Set/
│   ├── manifest.json
│   ├── New Order - Blue Monday.wav
│   └── Kraftwerk - Numbers.wav
└── Focus/
    ├── manifest.json
    └── ...
```

- **One directory per playlist** directly under `/library`. The directory name *is* the playlist
  name shown on the LCD.
- **Every audio file is 16-bit 44.1 kHz stereo PCM WAV** ([ADR 0002](decisions/0002-wav-not-mp3.md)).
  Files that are not are rejected at load with a specific reason.
- Firmware creates `/library` on first mount if it is absent.

## Names

The companion app sanitises names to **ASCII** before writing: accents transliterate
(`Björk` → `Bjork`), anything else becomes `_`, and an empty result becomes `untitled`.

This is deliberate. The firmware holds names in fixed byte buffers (`LIBRARY_NAME_MAX`, 64 bytes)
and renders them with a simple font, so a multi-byte character risks being truncated mid-sequence
and shown as mojibake.

## Limits

| Limit | Value | Where |
|---|---|---|
| Playlists | 64 | `LIBRARY_MAX_PLAYLISTS` |
| Tracks per playlist | 512 | `LIBRARY_MAX_TRACKS` |
| Name length | 64 bytes | `LIBRARY_NAME_MAX` |
| Path length | 128 bytes | `SD_PATH_MAX` |

Only one playlist's track list is held in RAM at a time — 512 × 64 B is 32 kB, which is
affordable; every playlist's tracks would not be.

## `manifest.json`

Written by the app beside the audio. It records what *should* be present, including tracks that
could not be resolved and why, so a later sync does not have to re-derive intent from filenames.

```json
{
  "name": "Late Night Set",
  "source_id": "spotify:playlist:...",
  "entries": [
    {
      "title": "Blue Monday",
      "artist": "New Order",
      "remote_path": "/library/Late Night Set/New Order - Blue Monday.wav",
      "isrc": "GBAAA8300001",
      "duration_ms": 449000,
      "resolver": "local"
    }
  ],
  "unresolved": ["Some Track — not found in local library"]
}
```

The firmware does not currently read the manifest — it enumerates directories directly, so the
card works even if the manifest is missing or stale. The manifest is for the app and for humans.

## Space

Roughly **10 MB per minute** (176 kB/s). A 32 GB card holds about 50 hours. The app estimates the
transcoded size with `estimate_wav_bytes()` and should check free space before starting, since a
part-written track is worse than one never started.

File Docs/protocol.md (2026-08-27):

# Device wire protocol

The link between the companion app and the firmware, over USB CDC serial.

**`Tools/protocol.toml` is the single source of truth.**

```
Tools/protocol.toml
   ├─► firmware header      (generation parked)
   └─► app Python module    (generation parked)
```

Both generators are written and working, but output is **parked** until each side decides where its
generated file lives. Set `H_OUT` / `PY_OUT` in `Tools/generate_protocol.py` to turn them back on.

With both parked, `--check` still validates the spec itself — duplicate opcodes, malformed entries —
so CI keeps a guard on this file.

```sh
python3 Tools/generate_protocol.py           # regenerate (once outputs are enabled)
python3 Tools/generate_protocol.py --check   # validate spec / check drift (CI runs this)
```

Never hand-edit either generated file.

## Framing

```
┌──────┬────────┬──────────────┬───────────────┬───────────┐
│ sync │ opcode │ length (LE16)│  payload      │ crc (LE16)│
│ 0xA5 │  1 B   │     2 B      │  0..512 B     │    2 B    │
└──────┴────────┴──────────────┴───────────────┴───────────┘
```

- **Sync** `0xA5` marks a frame boundary and carries no information.
- **Length** is little-endian and counts the payload only.
- **CRC** is **CRC-16/CCITT-FALSE** (poly `0x1021`, seed `0xFFFF`) over *opcode + length + payload* —
  everything except the sync byte. Transmitted little-endian.
- Maximum payload is **512 bytes**, matching the USB high-speed CDC packet size. Frame overhead is
  6 bytes.

A CRC rather than a checksum because the link carries bulk audio data, where one flipped bit must
not pass silently.

**Resynchronisation:** the decoder discards anything that is not a sync byte while idle. That is
what lets the link recover on its own after a corrupt frame, rather than one dropped byte killing
a long transfer.

> **Reference vector.** `CRC16("123456789") == 0x29B1`. Both test suites assert this. A frame
> carrying payload `01 02 03 04 05` with opcode `0x21` encodes to
> `a5 21 05 00 01 02 03 04 05 2a f6` on both sides, byte for byte.

## Commands — host to device

| Opcode | Name | Payload |
|---|---|---|
| `0x01` | `PING` | — |
| `0x02` | `GET_INFO` | — |
| `0x03` | `GET_STATUS` | — |
| `0x10` | `LIST_BEGIN` | UTF-8 path prefix |
| `0x11` | `LIST_NEXT` | — |
| `0x20` | `FILE_BEGIN` | `uint32` total size, then UTF-8 path |
| `0x21` | `FILE_CHUNK` | raw bytes |
| `0x22` | `FILE_END` | `uint32` CRC-32 of the whole file |
| `0x23` | `FILE_DELETE` | UTF-8 path |
| `0x30` | `SET_OUTPUT` | one `Output` byte |
| `0x40` | `DECK_LOAD` | `Deck` byte, then UTF-8 path |
| `0x41` | `DECK_TRANSPORT` | `Deck` byte, then `Transport` byte |

## Events — device to host

| Opcode | Name | Payload |
|---|---|---|
| `0x80` | `ACK` | the acknowledged opcode |
| `0x81` | `NACK` | acknowledged opcode, then a `Status` byte |
| `0x82` | `PONG` | — |
| `0x83` | `INFO` | protocol version, SD mounted flag |
| `0x84` | `STATUS` | deck A state, deck B state |
| `0x90` | `LIST_ENTRY` | flags byte, `uint32` size, UTF-8 name |
| `0x91` | `LIST_END` | — |
| `0xF0` | `LOG` | UTF-8 diagnostic text |

## Enumerations

**Status** — `OK 0x00`, `BAD_CRC 0x01`, `BAD_OPCODE 0x02`, `BAD_LENGTH 0x03`, `BAD_STATE 0x04`,
`SD_ERROR 0x05`, `NO_SPACE 0x06`, `NOT_FOUND 0x07`, `UNSUPPORTED 0x08`

**Output** — `ANALOG 0x00`, `BLUETOOTH 0x01`, `USB_HOST 0x02`
*(`USB_HOST` is accepted but always answered `NACK / UNSUPPORTED` — see [ADR 0005](decisions/0005-usb-host-audio.md).)*

**Deck** — `A 0x00`, `B 0x01`  ·  **Transport** — `STOP 0x00`, `PLAY 0x01`, `PAUSE 0x02`, `CUE 0x03`

## File transfer

```
app                                  device
 │── FILE_BEGIN (size, path) ───────►│  opens the file
 │◄────────────────── ACK ───────────│
 │── FILE_CHUNK (≤512 B) ───────────►│  appends, updates running CRC-32
 │◄────────────────── ACK ───────────│
 │        … repeat …                 │
 │── FILE_END (crc32) ──────────────►│  verifies, commits or deletes
 │◄────────────────── ACK ───────────│
```

The device verifies the CRC-32 before committing and **deletes the partial file on mismatch**. A
corrupt track is worse than a missing one: it would fail at play time, far from the transfer that
caused it.

Only one write may be open at a time. The protocol is strictly sequential, so a second
`FILE_BEGIN` is a protocol error rather than something to queue.

## Keeping the two sides honest

Opcodes and constants are generated, so they cannot disagree. The **framing** — the byte layout and
the CRC — has to be implemented once per language, and that is where silent divergence can creep in.

**Neither side is implemented yet.** When each is written, give both the same reference vectors:

```
CRC16("123456789")                  == 0x29B1
encode(FILE_CHUNK, 01 02 03 04 05)  == a5 21 05 00 01 02 03 04 05 2a f6
encode(PING)                        == a5 01 00 00 ac fb
```

Asserting those on both sides turns a divergence into a failing test rather than a link that
mysteriously does not work. Write those tests first — they are the contract between the two
codebases and cost nothing to run.

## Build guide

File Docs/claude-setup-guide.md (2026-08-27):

# Configuring Claude Code for this project

Written for someone setting up a project's AI configuration for the first time. It explains the
four mechanisms, when each is the right tool, and how this repository uses them.

The short version: **`CLAUDE.md` holds facts that are always true. Skills hold procedures you
invoke. Settings hold permissions. Hooks hold automation.** Most confusion comes from putting a
thing in the wrong one of those four.

---

## 1. The four mechanisms

| Mechanism | Lives in | Loaded | Good for |
|---|---|---|---|
| **`CLAUDE.md`** | repo root and subdirectories | automatically, every session | facts, constraints, conventions |
| **Skills** | `.claude/skills/<name>/SKILL.md` | when the model judges it relevant, or you type `/name` | multi-step procedures, checklists |
| **Settings** | `.claude/settings.json` | automatically | permissions, environment |
| **Hooks** | inside `settings.json` | on tool events | enforcement that must not be skipped |

### The distinction that matters most

**`CLAUDE.md` is always in context, so every line costs you.** A 500-line `CLAUDE.md` crowds out
the actual code. Put only what must be true in *every* conversation there.

**A skill costs nothing until it is used.** Long procedures, rarely-needed checklists and anything
conditional belong in a skill.

A useful test: *"Would I want this read before every single message?"* If no, it is a skill.

---

## 2. `CLAUDE.md` — one file or several?

You asked this directly. The answer for a monorepo like this one is **several**, arranged
hierarchically.

Claude Code reads the **root `CLAUDE.md` every session**, and picks up a **subdirectory's
`CLAUDE.md` when it works on files in that subdirectory**. So a nested file costs nothing while
you are working elsewhere.

This repository uses that shape:

```
Desk-Mixer/
├── CLAUDE.md             ← always loaded: repo map, hard facts, routing
├── Firmware/CLAUDE.md    ← only when touching firmware
├── App/CLAUDE.md         ← only when touching the app
└── Electrical/CLAUDE.md    ← only when touching the PCB
```

**What goes in the root file**

- A repository map, so the first question is never "where does this live?"
- **Hard facts that must not be silently re-derived.** This is the highest-value content in the
  whole setup. Our root file records that the SD card holds WAV not MP3, that USB host audio has
  no driver, and that Spotify is metadata-only. Without those, every new session risks
  cheerfully rebuilding something that was already decided and rejected — expensively.
- Pointers to the sub-project files.

**What goes in a sub-project file**

Anything only true inside it. The firmware file carries the byte-exact banner templates, the
real-time rules, and the pure/impure split. None of that is relevant while editing Python, so
none of it should be loaded then.

**What does *not* belong in any `CLAUDE.md`**

- Anything the code already says. It will drift, and the code wins.
- Long tutorials. Those are skills or `Docs/`.
- Aspirations. Write what is true now.

### Other placements

- `~/.claude/CLAUDE.md` — applies to *every* project you open. Good for personal style ("prefer
  British spelling"), bad for anything project-specific.
- `@path/to/file.md` inside a `CLAUDE.md` imports another file, which keeps the top-level file
  short.
- Typing `#` at the start of a message asks Claude to save a note to memory — the quickest way to
  capture a rule the moment you find yourself repeating it.

---

## 3. Skills

A skill is a folder containing `SKILL.md` with YAML frontmatter:

```markdown
---
name: firmware-module
description: Scaffold a new firmware subsystem module in the house style. Use when adding a
  new subsystem to the Teensy firmware, or when asked to create a new .h/.cpp pair.
---

# Steps

1. ...
```

The **`description` is the trigger.** The model reads descriptions to decide whether to load a
skill, so write it as *when to use this*, not *what this is*. "Scaffold a firmware module" is a
poor description; "Use when adding a new subsystem to the Teensy firmware" is a good one.

You can also invoke a skill explicitly by typing `/firmware-module`.

A skill folder can bundle scripts and reference files next to `SKILL.md`. That is often better
than describing a procedure in prose — our `doxygen-style` skill ships an actual checker rather
than explaining the rules again.

### The five skills in this repo

| Skill | Use when |
|---|---|
| `firmware-module` | adding a subsystem — generates the mirrored `.h`/`.cpp` with exact banners |
| `doxygen-style` | checking or fixing house style; runs `Tools/check_style.py` |
| `audio-graph` | touching the audio graph — CPU/memory budgeting and the 2.9 ms rules |
| `protocol-sync` | changing the wire protocol — regenerates both sides from the TOML |
| `preflight` | before committing — runs the whole local gate and reports a table |

Each earns its place by being repetitive and rule-heavy. **A skill that just restates `CLAUDE.md`
is worse than no skill**: it is another thing to keep in sync.

---

## 4. Settings and permissions

`.claude/settings.json` is committed and shared. `.claude/settings.local.json` is personal and
git-ignored.

The most immediately useful thing here is an allow-list, so routine read-only commands stop
prompting:

```json
{
  "permissions": {
    "allow": [
      "Bash(pio run:*)",
      "Bash(pio test:*)",
      "Bash(python3 Tools/check_style.py:*)"
    ]
  }
}
```

Two cautions worth internalising:

- Allow-list **read-only and idempotent** commands freely. Be deliberate about anything that
  writes, uploads, or pushes.
- Never allow-list `git push` or `git commit`. This repo's `CLAUDE.md` also says not to commit
  unless asked — belt and braces.

---

## 5. Hooks

Hooks run **your own shell commands** on tool events — `PreToolUse`, `PostToolUse`,
`UserPromptSubmit`, `Stop` and others. A `PreToolUse` hook can block a tool call.

The distinction from `CLAUDE.md`: a rule in `CLAUDE.md` is an instruction the model should follow;
a hook is machinery that runs whether or not the model cooperates. **If a rule genuinely must not
be violated, it wants a hook, not a sentence.**

For example, to run the style checker after every firmware edit:

```json
{
  "hooks": {
    "PostToolUse": [
      {
        "matcher": "Edit|Write",
        "hooks": [
          {
            "type": "command",
            "command": "python3 Tools/check_style.py 2>&1 | tail -5"
          }
        ]
      }
    ]
  }
}
```

This repo does **not** ship that hook, deliberately — it would run on every edit including the
Python app, where it is meaningless. The `.githooks/pre-push` gate covers the same ground at a
more sensible moment. Add the hook if you find style drift is actually happening.

---

## 6. Subagents

`.claude/agents/*.md` defines a subagent with its own context window and tool set. It is the right
tool when a task would otherwise flood your main conversation with output — a wide codebase search,
say — and you only need the conclusion.

Subagents cost a fresh context each time and cannot see your conversation, so they are not free.
This repo does not define any yet; the built-in general-purpose ones are enough at its current
size.

---

## 7. Deciding where something goes

```
Is it a fact that is always true?
   └─ yes ─► CLAUDE.md   (root if global, sub-project if scoped)
   └─ no
      │
      Is it a procedure with steps?
         └─ yes ─► skill
         └─ no
            │
            Must it be enforced mechanically?
               └─ yes ─► hook (or a git hook / CI job)
               └─ no ─► Docs/, and link it from CLAUDE.md
```

---

## 8. Keeping it honest over time

The failure mode for this kind of setup is not writing too little; it is letting it drift until it
is confidently wrong. Practical habits:

- **When a decision is made, write the ADR then**, not later. `Docs/decisions/` exists for this.
  Three of ours record decisions that had already silently changed in the schematic and were never
  written down — that is the state to avoid.
- **When you correct Claude twice on the same thing, that is a `CLAUDE.md` line.** Once is a
  mistake; twice is a missing rule.
- **Prefer generated over documented.** `Tools/protocol.toml` generates both protocol
  implementations, so they cannot disagree. A generator beats a paragraph asking two files to be
  kept in sync.
- **Prefer checked over asked.** `Tools/check_style.py` enforces the house style mechanically, so
  `CLAUDE.md` can state the rule once and point at the checker.
- **Reread the root `CLAUDE.md` every few months** and delete what is no longer true.

## 9. Where to start if you are extending this

1. Work normally, and notice when you repeat yourself.
2. Repeating a *fact* → add a line to the nearest `CLAUDE.md`.
3. Repeating a *procedure* → write a skill.
4. Repeating a *correction* → consider a hook or a checker.
5. Making an architectural *decision* → write an ADR.

Nothing here needs to be got right up front. The configuration is meant to grow out of friction
you actually hit.

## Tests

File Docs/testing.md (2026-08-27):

# Testing

## The honest constraint first

**There is no Teensy 4.1 emulator.** No Renode or QEMU machine model exists for the i.MX RT1062,
and the peripherals that actually matter here — SAI/I2S, USDHC/SDIO, the audio engine's interrupt
timing — are not modelled anywhere. Do not go looking for an emulation tier; it does not exist.

Everything below is built around that fact. The strategy is to make as much of the firmware as
possible *not need hardware*, and to be explicit about the part that does.

## Tiers

| # | Tier | Command | Runs in CI |
|---|---|---|---|
| 1 | Firmware host unit tests | `pio test -e native` | when suites exist |
| 2 | App unit tests | `pytest` | when suites exist |
| 3 | Firmware build | `pio run -e teensy41` | yes |
| 4 | Static analysis + style | `cppcheck`, `ruff`, `mypy`, `check_style.py` | yes |
| 5 | Protocol spec | `python3 Tools/generate_protocol.py --check` | yes |
| 6 | On-target tests | `pio test -e teensy41_test` | **no** — needs hardware |

### Tier 1 — hardware-independent firmware code

**No firmware modules exist yet.** The recommendation, when they do: keep the parts that make
*decisions* in files with **no Arduino, Teensy or hardware headers** — only `<stdint.h>`,
`<stddef.h>`, `<string.h>`, `<math.h>`.

Those files can be compiled and run on the laptop, which is the only automated firmware testing
available here. Candidates that tend to fall out naturally:

```
framing and checksums     deterministic byte-in, byte-out
gain and fader curves     pure arithmetic with invariants worth asserting
format parsing            e.g. a WAV header, given a buffer
menu and selection logic  index maths, no drawing
input conditioning        debounce and scaling, given a caller-supplied clock
```

Listing such a file in `[pure] sources` in `platformio.ini` is what makes `[env:native]` compile it.
A file that is not listed is never host-tested and nobody notices.

The question to ask when adding logic: **can this be decided without touching hardware?** If yes,
it can be tested; if it is tangled with peripheral calls, it cannot.

### Tier 2 — the app

**Not built yet.** The app is scaffolding; `App/README.md` holds the design and the build order.

The rule to hold to when it is built: **no test may touch the network, a real serial port, or a
real ffmpeg binary.** That stays achievable if the layering holds — everything except `ui/` usable
headless. Three fakes carry most of it:

- a **loopback transport** standing in for the serial link, able to play a fake device that ACKs or
  NACKs, so the whole transfer flow runs with no hardware;
- building the **ffmpeg argument vector separately from running it**, so the invocation is asserted
  without invoking anything;
- **captured JSON payloads** through the Spotify mapping function.

### Tier 5 — cross-implementation agreement

Opcodes and constants come from `Tools/protocol.toml`, so they cannot drift once generation is
enabled. The framing has to be implemented once per language, and **neither side is written yet**.
When they are, both should assert the **same reference vectors**:

```
CRC16("123456789")                     == 0x29B1
encode(FILE_CHUNK, 01 02 03 04 05)     == a5 21 05 00 01 02 03 04 05 2a f6
encode(PING)                           == a5 01 00 00 ac fb
```

If either side drifts, a test fails rather than the link mysteriously breaking. While generation is
parked, `--check` still validates the spec — duplicate opcodes and malformed entries.

### Tier 6 — on-target

For what genuinely cannot be faked: SD throughput, I²C enumeration of the SGTL5000, the BM83 UART
handshake, and real audio CPU load.

Note the BM83 will not answer at all until it has been switched to Host Mode with Microchip's
Config Tool — a hardware provisioning step, not a firmware bug.

Two caveats:

- **PlatformIO claims the first `Serial` as its test transport**, so every `Serial` use in the
  firmware must sit inside `#ifndef UNIT_TEST`.
- Teensy 4.1 on-target runs are known to stall after upload occasionally. This tier is a **local
  gate, not a CI gate**.

## What is not covered, and is known not to be

Stated plainly so nobody assumes otherwise:

- Audio timing under load. `AudioProcessorUsageMax()` must be read on hardware.
- SGTL5000 register behaviour — no I²C fake.
- BM83 behaviour. The packet codec is tested; the module's responses are not, and it must be
  switched to Host Mode with Microchip's Config Tool before it responds at all
  ([ADR 0003](decisions/0003-bluetooth-bm83.md)).
- The display driver — the panel has not been chosen.
- Real Spotify API responses.

## Local gate

```sh
# firmware
cd Firmware && pio run -e teensy41       # add `&& pio test -e native` once suites exist
# app
cd App && .venv/bin/ruff check .         # add pytest and mypy once modules exist
# cross-project
python3 Tools/check_style.py
python3 Tools/generate_protocol.py --check
```

`.githooks/pre-push` runs the same checks, so local and CI agree. Enable it once:

```sh
git config core.hooksPath .githooks
```

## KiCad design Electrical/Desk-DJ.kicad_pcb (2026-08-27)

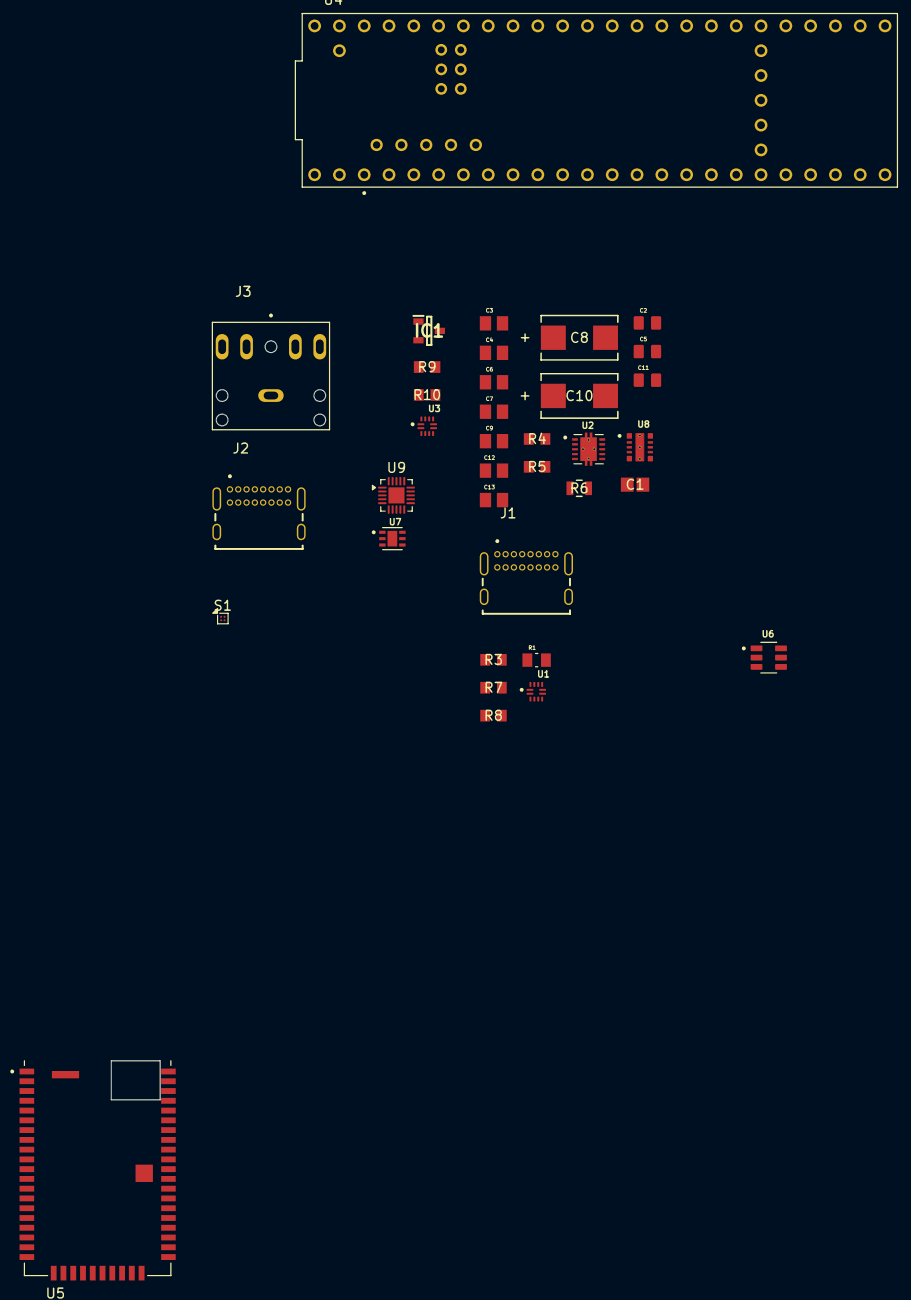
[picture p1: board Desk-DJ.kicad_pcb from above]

Board: 2 copper layers, 36 parts (0 on the bottom side), 35 nets, no tracks yet.

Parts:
C1: C0805C102K5RACTU; CAPC220145_88N_KEM
C2, C5, C11: CL21B105KBFNNNE; CAPC2012X135N
C3, C6, C12: C0805C473K5RACTU; CAPC2012X88N
C4, C7, C9, C13: C0805C100JDGACTU; CAPC2012X140N
C8, C10: T520D227M010ATE040; CAPMP7.6X4.3_3.1N_KEM
IC1: AP7313-18SRG-7; SOT96P240X135-3N
J1, J2: USB4085-GF-A_REVA4; GCT_USB4085-GF-A_REVA4
J3: SJ1-3525N; CUI_SJ1-3525N
R1: RMCF0805ZT0R00; RESC2012X65N
R3: CRCW0805887KFKEA; RC0805N_VIS
R4, R5: RC0805FR-07100KL; RC0805N_YAG
R6: CRCW0805560KFKEA; RES_CRCW_0805
R7, R8, R9, R10: ERJ-6GEYJ473V; RC0805N_PAN
S1: TL3365AF180QG; WLCSP-4_0.64x0.64mm_Layout2x2_P0.35mm
U1, U3: TUSB320RWBR; IC_TUSB320RWBR
U2: TPS259251DRCT; VREG_V62_16624-01YE
U4: DEV-16771; MODULE_DEV-16771
U5: BM83SM1-00TA; XCVR_BM83SM1-00TA
U6: USBLC6-2SC6; SOT95P280X145-6N
U7: TPS2552DRVR; SON65P200X200X80-7N
U8: TPSM82903SISR; IC_TPSM82903SISR
U9: SGTL5000XNLA3; QFN-20-1EP_3x3mm_P0.4mm_EP1.65x1.65mm

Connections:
3V3_PG: U4.34 (RX8), U8.6 (PG)
+3.3V: C10.1, C11.2, C12.1, C13.1, R8.1, R10.1, U1.12 (VDD), U3.12 (VDD), U8.9 (VOUT), U8.10 (VOUT__1)
+5V: C5.2, C6.1, C7.1, C8.1, C9.1, R5.2, U2.6 (VOUT-2), U2.7 (VOUT-1), U2.8 (VOUT), U4.5V, U4.VIN, U4.VUSB, U7.6 (IN), U8.1 (VIN), U8.2 (VIN__1), U8.3 (EN), U8.4 (MODE/S-CONF)
GND: C1.2, C2.1, C3.2, C4.2, C5.1, C6.2, C7.2, C8.2, C9.2, C10.2, C11.1, C12.2, C13.2, J1.A1 (GND), J1.A12 (GND), J1.B1 (GND), J1.B12 (GND), J1.S1 (SHELL), J1.S2 (SHELL), J1.S3 (SHELL), J1.S4 (SHELL), J2.A1 (GND), J2.A12 (GND), J2.B1 (GND), J2.B12 (GND), J2.S1 (SHELL), J2.S2 (SHELL), J2.S3 (SHELL), J2.S4 (SHELL), R1.1, R4.1, R6.2, R7.2, R9.2, U1.3 (PORT), U1.10 (GND), U3.10 (GND), U4.GND1 (GND), U4.GND2 (GND__1), U4.GND3 (GND__2), U4.GND4 (GND__3), U4.GND5 (GND__4), U4.USB_GND1 (USB_GND), U4.USB_GND2 (USB_GND__1), U6.2 (GND), U8.11 (GND), U9.21 (GND)
I2C_SCL: U3.8 (SCL/OUT2), U9.19 (CTRL_CLK)
I2C_SDA: U3.7 (SDA/OUT1), U4.18 (A4), U9.18 (CTRL_DATA)
I2S1_BCLK: U4.21 (A7), U9.15 (I2S_SCLK)
I2S1_LRCLK: U4.20 (A6), U9.14 (I2S_LRCLK)
I2S1_MCLK: U4.23 (A9), U9.13 (SYS_MCLK)
I2S1_TEENSY_IN: U4.7 (RX2), U9.16 (I2S_DOUT)
I2S1_TEENSY_OUT: U4.8 (TX2), U9.17 (I2S_DIN)
unnamed: J1.A5 (CC1), U1.1 (CC1)
unnamed: J1.B5 (CC2), U1.2 (CC2)
unnamed: J1.A7 (DN1), J1.B7 (DN2), U6.3 (D-_IN)
unnamed: J1.A6 (DP1), J1.B6 (DP2), U6.1 (D+_IN)
unnamed: J2.A5 (CC1), U3.1 (CC1)
unnamed: J2.B5 (CC2), U3.2 (CC2)
unnamed: R8.2, U1.5 (ADDR)
unnamed: R1.2, U1.9 (ID)
unnamed: R3.1, U1.4 (VBUS_DET)
unnamed: R7.1, U1.11 (~EN_N)
unnamed: C1.1, U2.1 (DV/DT)
unnamed: R5.1, R6.1, U2.2 (EN/UVLO)
unnamed: R4.2, U2.10 (ILIM)
unnamed: R9.1, U3.5 (ADDR)
unnamed: U3.9 (ID), U7.4 (~EN)
unnamed: R10.2, U3.3 (PORT)
unnamed: J3.2, U9.4 (HP_L)
unnamed: J3.3, U9.1 (HP_R)
unnamed: J3.1, U9.2 (HP_VGND)
TEENSY_3V3_OUT: U4.3.3V_1 (3.3V), U4.3.3V_2 (3.3V__1), U4.3.3V_3 (3.3V__2)
USBC_5V_FLT: U4.31 (CTX3), U7.3 (~FAULT)
USBC_AUDIO_DET: U3.6 (~INT_N/OUT3), U4.30 (CRX3)
USBC_AUDIO_EN: U3.11 (~EN_N), U4.35 (TX8)
VBUS: C2.2, C3.1, C4.1, J1.A4 (VBUS), J1.A9 (VBUS), J1.B4 (VBUS), J1.B9 (VBUS), J2.A4 (VBUS), J2.A9 (VBUS), J2.B4 (VBUS), J2.B9 (VBUS), R3.2, U2.3 (VIN-1), U2.4 (VIN), U2.5 (VIN-2), U6.5 (VBUS), U7.1 (OUT)

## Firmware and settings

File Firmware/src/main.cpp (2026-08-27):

/**************************************************************************************************/
/**
 * @file main.cpp
 * @author  Ryan Jing
 * @brief Firmware entry point. Cooperative superloop with fixed-cadence tasks.
 *        Subsystems are added as they are built -- see README.md for the integration notes.
 *
 * @version 0.1
 * @date 2026-08-26
 *
 * @copyright Copyright (c) 2026
 *
 */
/**************************************************************************************************/

/*------------------------------------------------------------------------------------------------*/
/* HEADERS                                                                                        */
/*------------------------------------------------------------------------------------------------*/

#include <Arduino.h>

/*------------------------------------------------------------------------------------------------*/
/* MACROS                                                                                         */
/*------------------------------------------------------------------------------------------------*/

// Serial diagnostics. Never call Serial from the audio path -- the audio engine
// runs at interrupt priority on a 2.9 ms deadline and logging will cause dropouts.
#define PRINT_DEBUG 1

// Task cadences in milliseconds. Chosen so the worst-case latency of each task is
// obvious by inspection rather than emergent from a scheduler.
#define CONTROL_PERIOD_MS 1
#define LINK_PERIOD_MS 2
#define DISPLAY_PERIOD_MS 30

/*------------------------------------------------------------------------------------------------*/
/* GLOBAL VARIABLES                                                                               */
/*------------------------------------------------------------------------------------------------*/

// Last run time per task. Compared against millis() in loop().
static uint32_t s_last_control_ms = 0;
static uint32_t s_last_link_ms = 0;
static uint32_t s_last_display_ms = 0;

/*------------------------------------------------------------------------------------------------*/
/* FUNCTION PROTOTYPES                                                                            */
/*------------------------------------------------------------------------------------------------*/

/**************************************************************************************************/
/**
 * @name
 * @brief Poll the control surface and apply changes.
 *        Runs at the fastest cadence: this is what makes the device feel responsive.
 *
 *
 */
/**************************************************************************************************/
static void control_task(void);

/**************************************************************************************************/
/**
 * @name
 * @brief Service the host link and any module UARTs.
 *        Kept off the control cadence so a busy host cannot starve the controls.
 *
 *
 */
/**************************************************************************************************/
static void link_task(void);

/**************************************************************************************************/
/**
 * @name
 * @brief Redraw the display.
 *        Slowest cadence -- an SPI panel refresh is expensive and the eye is not.
 *
 *
 */
/**************************************************************************************************/
static void display_task(void);

/*------------------------------------------------------------------------------------------------*/
/* FUNCTION DEFINITIONS                                                                           */
/*------------------------------------------------------------------------------------------------*/

static void control_task(void) {
}

static void link_task(void) {
}

static void display_task(void) {
}

void setup() {
    #ifdef PRINT_DEBUG
        Serial.begin(115200);
    #endif

    // Subsystem initialisation goes here, in dependency order. Bring up anything
    // the audio engine depends on before the engine itself, and let a failed
    // subsystem report and continue rather than blocking startup -- a missing SD
    // card should still leave a usable device.
}

void loop() {
    uint32_t now = millis();

    // Cooperative superloop rather than an RTOS. The Teensy audio library already
    // preempts from an interrupt, so the only job here is to run each task often
    // enough without any of them blocking. Nothing in this loop may busy-wait or
    // call delay(); a task that needs to wait should return and resume next tick.
    if ((now - s_last_control_ms) >= CONTROL_PERIOD_MS) {
        s_last_control_ms = now;
        control_task();
    }

    if ((now - s_last_link_ms) >= LINK_PERIOD_MS) {
        s_last_link_ms = now;
        link_task();
    }

    if ((now - s_last_display_ms) >= DISPLAY_PERIOD_MS) {
        s_last_display_ms = now;
        display_task();
    }
}

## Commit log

2026-07-18 Added schematics
    [Audio_IO.kicad_sch, Desk-DJ.kicad_pcb, Desk-DJ.kicad_sch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]
2026-08-27 Restructuring project a little, I want to learn how to incorporate Claude into my development process properly
    [Audio_IO.kicad_sch, Desk-DJ.kicad_pcb, Desk-DJ.kicad_sch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]
